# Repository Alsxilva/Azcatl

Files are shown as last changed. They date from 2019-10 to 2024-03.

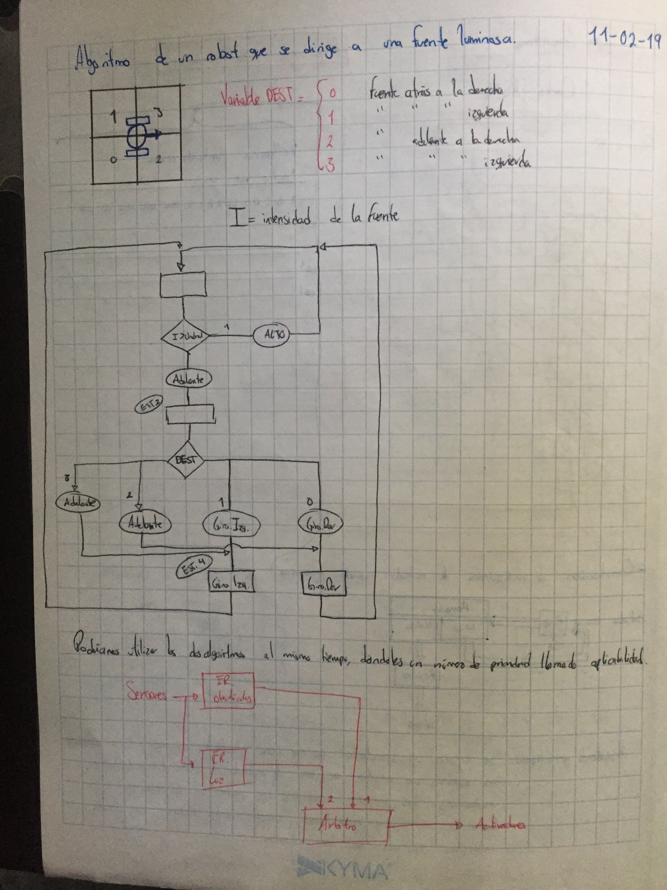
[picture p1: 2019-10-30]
Documentación/Máquinas de estado/IMG_5839.JPG

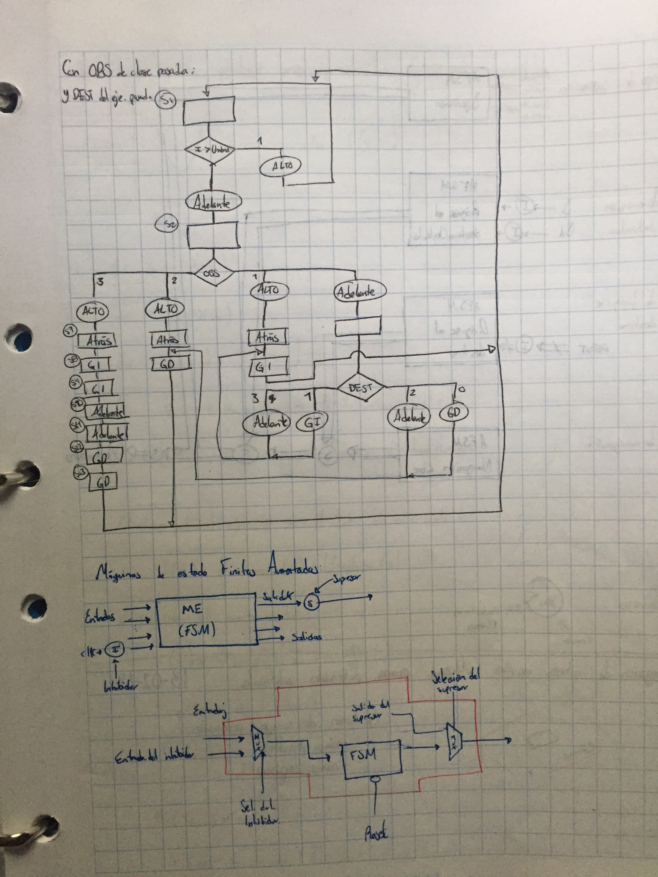
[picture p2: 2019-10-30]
Documentación/Máquinas de estado/IMG_5840.JPG

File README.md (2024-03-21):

# Azcatl 🐜 

Proyecto Azcatl de la Facultad de Ingeniería, UNAM. 
Laboratorio de Bio-Robótica.

## Encargado
Dr. Jesús Savage Carmona

## Colaboradores actuales del proyecto
* Silva Guzmán Alejandro

## Colaboradores pasados del proyecto
* Medrano Albarrán Gerardo 
* Merino Texta Rogelio de Jesús
* Silva Guzmán Edgar Roberto

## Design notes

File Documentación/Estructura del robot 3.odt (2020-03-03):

Estructura del robot

Fotoresistensias: vector de 8 elementos.

Elemento que ocupa dentro del arreglo:

Elemento del vector | Posicion en la estrella | Estado
4 | 1 | Correcto
3 | 2 | Correcto
2 | 3 | Falso: Solucionado
1 | 4 | Correcto
0 | 5 | Correcto
7 | 6 | Falso en jumper: ajustar
6 | 7 | Correcto
5 | 8 | Falso en jumper: ajustar

Reparado:

Elemento del vector | Posicion en la estrella | Estado
0 | 1 | Correcto
1 | 2 | Correcto
2 | 3 | Correcto
3 | 4 | Correcto
4 | 5 | Correcto
5 | 6 | Correcto
6 | 7 | Correcto
7 | 8 | Correcto

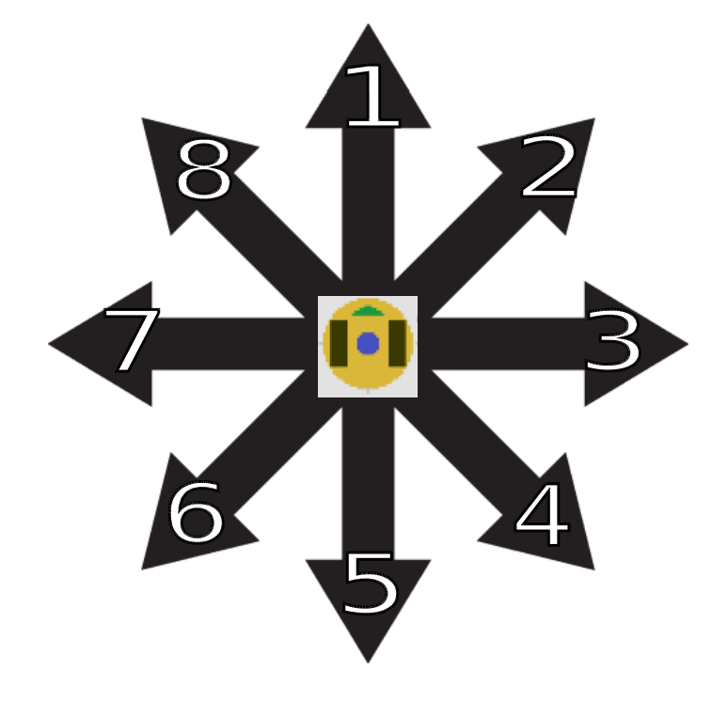
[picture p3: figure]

Intensidad de luz:

El arduino hace una conversión analógica-digital del valor entregado por las resistencias. Este valor lo recoge y lo asigna a un valor de 10 bits, siendo el valor mínimo 50 y el máximo 1023.

Si en las lecturas aparece un valor menor a 50, es que esta fotoresitencia tiene un falso contacto, seguramente en la pata unida al jumper (checar diagrama de posición de fotoresitencias).

A continuación se muestran los rangos utilizados en el programa:

Intensidad de luz | Rango | En valores que entrega arduino
Débil | 30-50% | 341 - 536
Media | 50-70% | 536 - 731
Alta | 70-90% | 731 - 875
Muy alta | 90-100% | 875 - 1023

Hokuyo

Izq: de 80 a 90°

CentralIzq: de 20 a 30°

Central: de 10 a 20 °

CentralDer: de 0 10 °

Der: -60 a -50 °

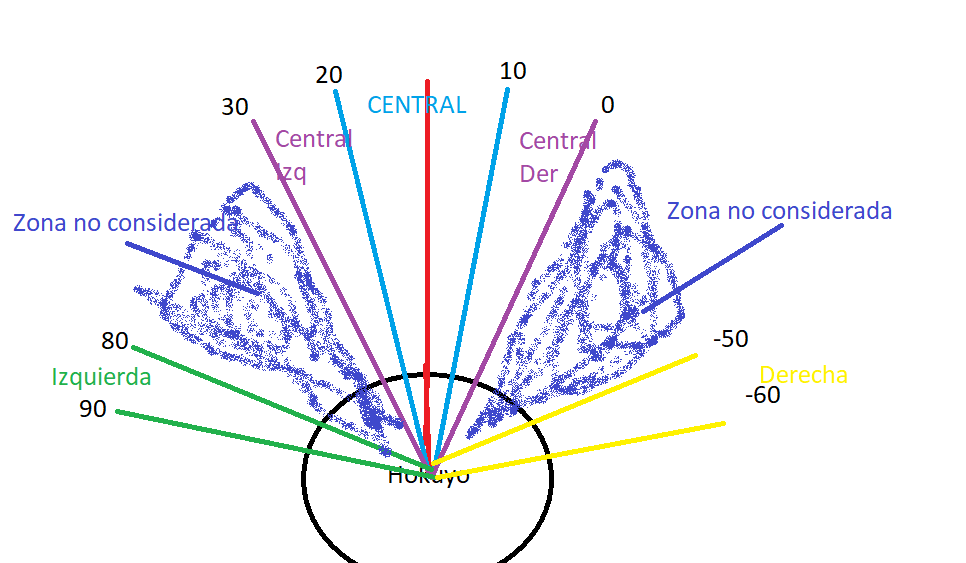
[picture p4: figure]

IMU:

Instalar para linux desde la Repo

-Demo GL: IC² y Kalman

-C++

-Python setup.py

-RTIMULib leer

Calibracion desde .exe

Regulador de voltaje:

https://www.pololu.com/product/2111

Controlador de motores:

https://www.pololu.com/product/2502/pictures

Motores:

https://www.pololu.com/product/4755/pictures

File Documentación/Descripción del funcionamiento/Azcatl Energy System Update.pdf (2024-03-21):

## Universidad Nacional Autónoma de México Posgrado de Ingeniería Laboratorio de Biorobótica

# Robot Móvil “Azcatl"

## Consumo de Energía

## A cargo de: Dr. Savage Carmona Jesús

## Realiza: Silva Guzmán Alejandro

## 19 de marzo de 2024

FACULTAD DE INGENIERÍA | 1

## I. Introducción

En el presente documento surge como respuesta y complemento al análisis del comportamiento visto en el robot Ázcatl con su configuración actual(1), la cual experimentalmente dista de su respuesta ideal. A la par del refinamiento en su Lógica de Comportamiento (2) se propone un arreglo distinto en su conexión eléctrica, pues como se describirá en los siguientes párrafos, parte de la respuesta no ideal de algunos componentes es debido a un suministro de energía erróneo.

II. Mejoras al funcionamiento.

Con el objetivo de perfeccionar el algoritmo que permita al robot rotar y trasladarse una cantidad exacta de unidades de medida (ángulo de rotación [º] o distancia [m]) se realizaron pruebas en su última configuración implementada. Pese a unos resultados parcialmente positivos durante las pruebas en el funcionamiento del robot ejecutando los algoritmos “seguidor de luz” y “evasor de obstáculos”, así como su versión de ejecución paralela, se detectaron errores y posibles mejoras, divididos en dos principales ámbitos.

II.I. Errores prácticos

Estos errores se detectaron durante la ejecución práctica de los algoritmos en el robot en un ambiente real controlado.

A. El ángulo rotado y la distancias recorridas durante estas ejecuciones fue únicamente exitoso bajo la experimentación: observación en el comportamiento, re-ajuste de parámetros y de nuevo ejecución hasta llegar al comportamiento deseado. En la mayoría de las ocasiones, aún variados los coeficientes del Perfil Trapezoidal de Movimiento, la cantidad de unidades de medida deseadas terminaron siendo casi duplicadas para alcanzar la unidad deseada.
- Ejem: Cantidad deseada: 50[cm]
Cantidad necesaria a introducir: 95[cm]

Aunque menos comunes, también se detectaron errores en los componentes:
B. Paro total en el movimiento de los seis motores. Los encoders así como los demás componentes siguen funcionando correctamente durante este error.

C. Paro parcial en el movimiento de un motor (medio-izquierda). La conexión de este motor parece estar sufriendo de un punto de conexión débil que no le suministra la energía total necesaria (Punto exacto aún no detectado). Los demás componentes siguen funcionando correctamente durante este error.
D. Pérdida de la conexión entre Ázcatl y Controlador.

II.II.Errores teóricos

Estos errores surgen tras el análisis del comportamiento erróneo del Robot, aunado a que la mayoría de los fallos ocasionales están más relacionados a la parte eléctrico-mecánica.

1. Se encontró que la energía necesaria para una ejecución de máxima eficiencia en los motores es de 12[V] mientras que se les estaba suministrando 7.4[V], lo que supone una variación en la energía otorgada y por lo tanto en el comportamiento final de los motores.

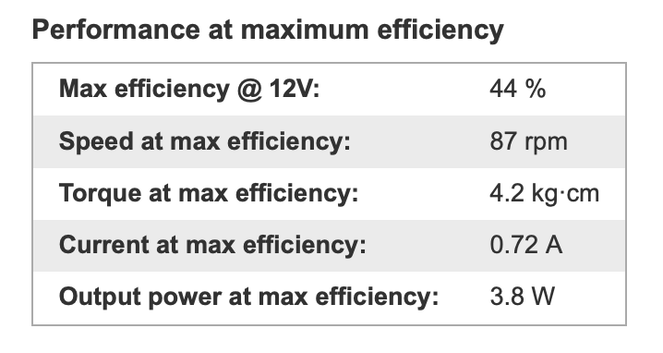
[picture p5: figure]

2. Fallo de suministro de energía. Las baterías utilizadas ya muestran signos de deterioro, y a pesar de servir parcialmente lo más probable es que ya no funcionen ni cerca de su comportamiento ideal, derivando en fallos del suministro de energía total necesaria para el robot y finalmente en alguno de los errores listados anteriormente (Errores A, B, C y D).

En vías de llegar al comportamiento óptimo del robot se propone una conexión eléctrica distinta con un suministro eléctrico distinto como resolución principal al problema planteado, anteponiéndose por ahora a la resolución por software (implementación de un IMU). Estas propuestas se describen en el punto final y siguiente.

1.1 Pololu Gearmotor 37Dx73L Datasheet

III. Análisis y cálculo del consumo de energía por módulos.

Se propone dividir la conexión eléctrica en dos módulos, alimentados por 12 [V] y 5 [V] respectivamente.

Este arreglo nos permite dividir los componentes de consumo alto y variable (motores) de los de consumo normal y continuo (CPUs y periféricos), lo cual nos brinda las siguientes ventajas:

- Motores trabajando con el Voltaje de máxima eficiencia para movimientos más exactos.
- Mayor potencia en los motores que permitirá reducir tiempos de ejecución.
- Permitirá una identificación más sencilla de los problemas en ejecución gracias al aislamiento por módulos.
- Protección de nuestras tarjetas ante alguna sobrecarga o falta de energía gracias al aislamiento por módulos.
- Conexión de un mayor número de periféricos para trabajos futuros (IMU, Control, etc).
- Mejora drástica en el aprovechamiento de energía de las baterías.

12[V]

6 Pololu Gearmotor

5[V]

2 LEDs
Hokuyo
Arduino Mega
Raspberry pi 3+

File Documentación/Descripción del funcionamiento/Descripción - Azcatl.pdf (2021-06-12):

## Universidad Nacional Autónoma de México Posgrado de Ingeniería Laboratorio de Biorobótica

# Robot Móvil “Azcatl"

## Servicio Social

# Reporte de modificaciones

## A cargo de: Dr. Savage Carmona Jesús

## Realiza: Silva Guzmán Alejandro

## 23 de Marzo de 2020

FACULTAD DE INGENIERÍA | 1

## Reporte de modificaciones

1. Reparación y sustitución de torre de fotoresistencias
El elemento presentaba fallas constantemente debido al desgaste de los componentes: había cables “jumpers” muy desgastados a las puntas, lo cual provocaba un falso contacto; algunas fotoresistencias presentaban fallos en sus pines, las cuales fueron sustituídas.
Además se sustituyó la antigua estructura (taparrosca redonda) dado que no brindaba el espacio necesario para un acomodo adecuado de las fotoresistencias. Y finalmente se agregaron dos luces led que indican el estado Encendido/Apagado del Arduino.
La torre quedó de la siguiente manera.

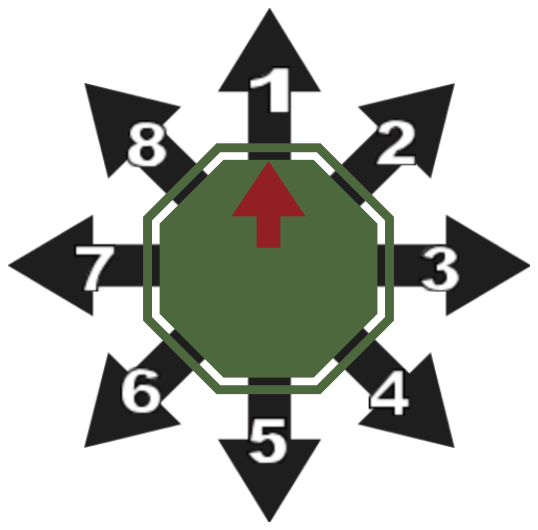
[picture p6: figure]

Figura muestra el orden de las fotoresistencias y la posición de cada una de ellas dentro del arreglo usado por el algoritmo.

2. Elaboración de nuevos cables de alimentación desde baterías muertas (inservibles)
Se pidió la nueva batería que se requerían para el funcionamiento prolongado del robot: 7.4[V] con capacidad de 5000[mA]. Misma que requería una conexión de alimentación “XT30”; se adaptó a la conexión que ya tenía el robot, que es la “T-System AWG12”:
3. Documentación de códigos “Arduino control”, “carrito_node”, “simple_move_node”. Estos códigos fueron realizados anteriormente, pero no contaban con un formato adecuado, ni con comentarios que facilitaran su entendimiento.
4. Se le realizó mantenimiento diversas partes del robot:
- Ajuste de llantas: estaban ya fuera de su posición.
- Ajuste de esqueleto del robot: estaba desajustado y desnivelado.

- Agregué soporte a motores de las 6 llantas del robot: se agregó una escuadra metálica a cada uno de los motores en las llantas, pues por el desgaste, los ejes de las llantas ya estaban fuera de su posición, provocando que cada llanta girara en sentidos distintos, provocando una desviación significante en el comportamiento del robot.
Desviación apreciable en largas distancias rectas: el robot se desviaba aproximadamente 15[cm] a la derecha por 1[m] recorrido en línea recta.
Estos soportes mejoran en gran medida este comportamiento, obteniendo una desviación de menos de 3[cm] por metro recorrido en línea recta.
*Insertar foto de los soportes de las llantas”
5. Creación de nodo “simple_move_2”.
Este nuevo nodo de ROS fue hecho específicamente para calibrar el movimiento del robot. En él, únicamente se indican por teclado los siguientes parámetros:
- El número de pasos
- La distancia (en metros) por paso
- El ángulo (en grados) por paso
- Las constantes “K” para el control PID
6. Creación de nodos de comportamiento reactivo: “evasor_obstaculos_hokuyo” y “seguidor_de_luz”.
6.1.Para el nodo de evasión de obstáculos se utilizó parte de la máquina de estados utilizada para el seguimiento de color en el proyecto pasado.
Para este nodo el usuario ingresarán cuatro parámetros: el número de pasos, la distancia y ángulo de giro (por paso) y la distancia a detectar los obstáculos.
La visión del láser Hokuyo se es la siguiente:

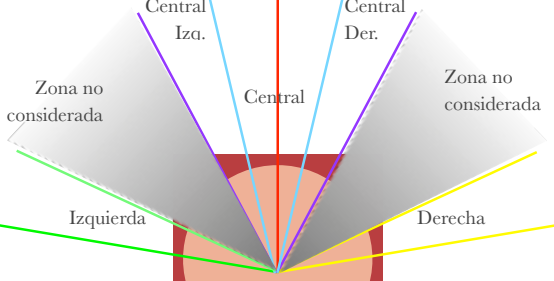
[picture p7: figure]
Izquierda; Derecha; Zona no considerada; Izq.; Central; Der.

Se hace un barrido para detectar la o las zonas de dónde se encuentra un posible

Hokuyo

Central

Central

obstáculo.
El algoritmo está descrito como se muestra a continuación:

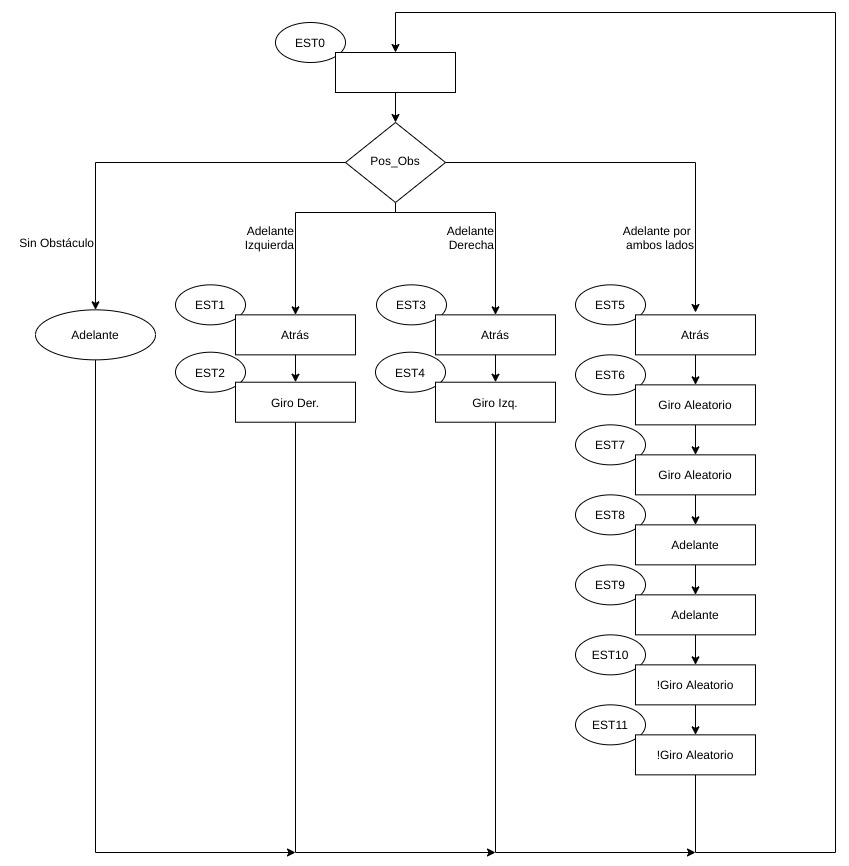
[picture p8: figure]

6.2.Para el nodo de seguimiento de luz, el usuario ingresarán cuatro parámetros: el número de pasos, la distancia y ángulo de giro (por paso) y la intensidad a detectar la luz los obstáculos.
El algoritmo está descrito como se muestra a continuación:

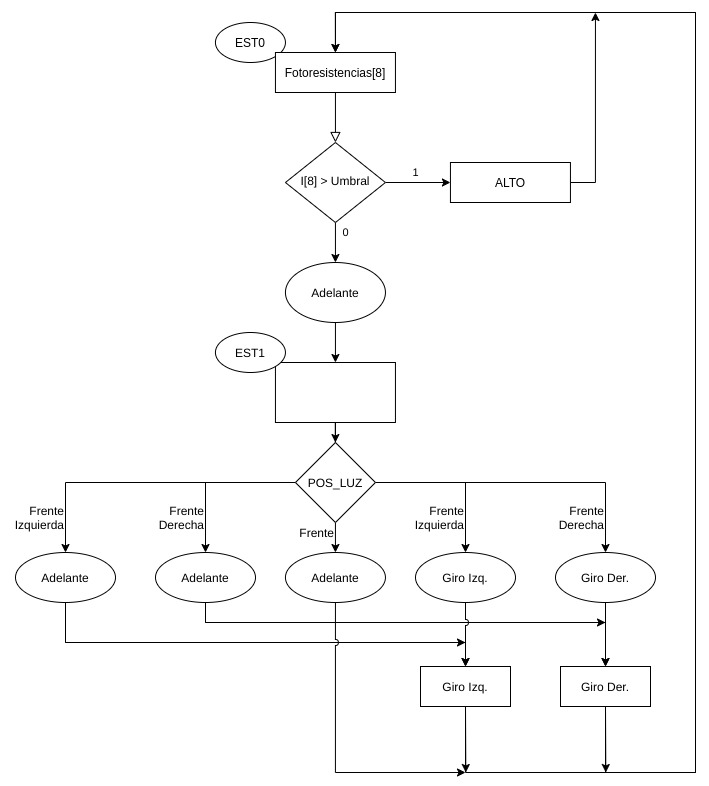
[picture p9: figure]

7. Implementación de un USB hub para correcta alimentación de Arduino y Hokuyo del robot Azcatl.
Anteriormente estos dispositivos de alimentaban directo de la tarjeta RaspberryPi, pero constantemente había un fallo: los puertos USB de esta tarjeta están limitados a cierta potencia, y al llegar al límite, ocasionaba un parón en los motores y en la Arduino, perdiendo la comunicación entre ellos y fallando así por completo la ejecución del algoritmo en uso.
8. Creación de nuevo repositorio en Github
La liga es la siguiente:
https://github.com/Alsxilva/Azcatl

En este repositorio fui registrando todos los avances durante el servicio social:
- Documentación del código: ordenar y comentar el código ya implementado para su mejor y más fácil entendimiento
- Actualización constante de nuevos nodos creados “simple_move_2”, “seguidor_luz” y “seguidor_obstaculos”.
- Almacenamiento de archivos importantes del Azcátl: archivo de descripción .PDF y demás documentación necesaria.

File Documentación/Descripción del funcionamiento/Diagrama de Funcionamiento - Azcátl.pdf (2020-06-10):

## Universidad Nacional Autónoma de México Posgrado de Ingeniería Laboratorio de Biorobótica

# Robot Móvil “Azcatl"

## Servicio Social

# Diagrama de Funcionamiento

## A cargo de: Dr. Savage Carmona Jesús

## Realiza: Silva Guzmán Alejandro

## 20 de abril de 2020

FACULTAD DE INGENIERÍA | 1

## Descripción

1. Estructura
El robot Azcatl cuenta con dos principales unidades de procesamiento:
- Una RaspberryPi 3
- Arduino Mega
A su vez, el Arduino cuenta con un elemento de control para los motores:
- Pololu Dual VNH5019 Motor Driver Shield para Arduino
Y la distribución de funcionamiento se describe en el siguiente diagrama:

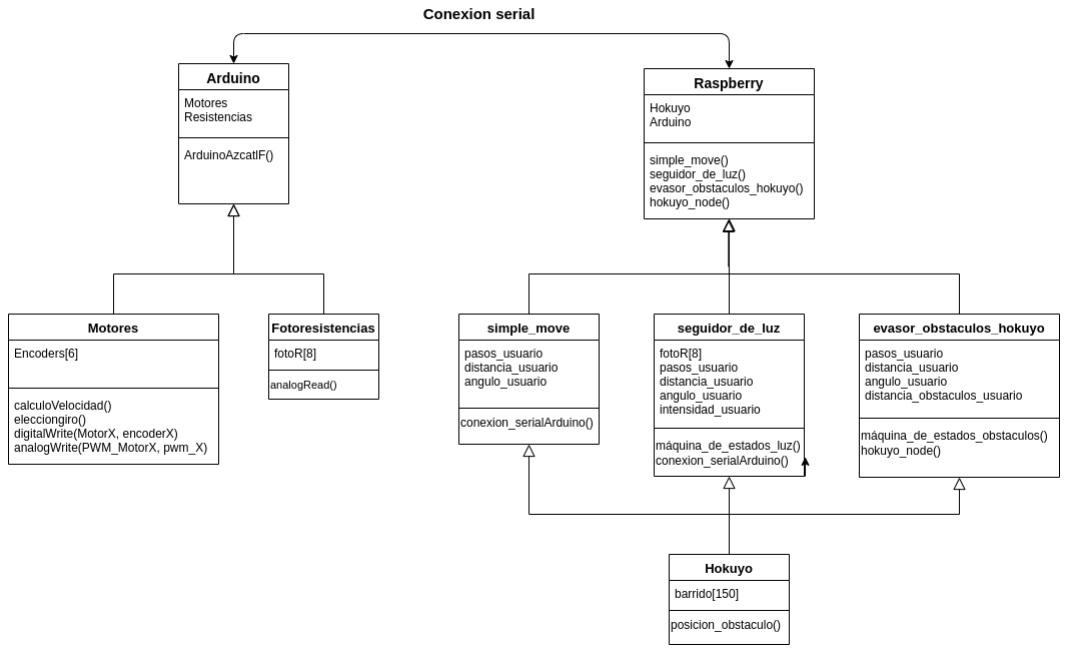
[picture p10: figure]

2. Conexión serial
Anteriormente la comunicación entre el Arduino y la Raspberry se realizaba mediante ROS. Se iniciaba un nodo desde el Arduino en el cual se publicaban y se recibían los datos. Esta misma estructura tuvo ciertas limitaciones: al intentar publicar más datos, nos encontramos con un tope en el ancho de comunicación, pues el tamaño del buffer mediante el cual se transmitían los datos se era insuficiente. Esto, además de impedir la prueba de algunos algoritmos dentro del robot, llegó a causar la nula sincronización y/o desconexión entre las tarjetas, por lo cual se cambió la manera en que estos se comunican.
Esta conexión ahora es directa por el puerto serial (USB 2.0 Type-B) por la que se conectan las tarjetas.

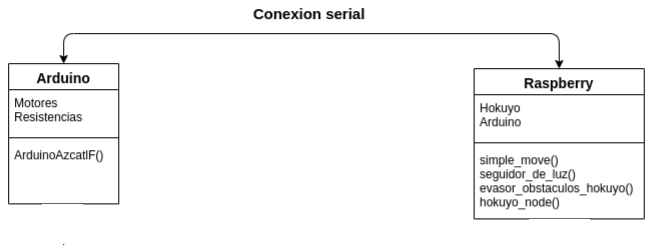
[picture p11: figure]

3. Arduino Mega

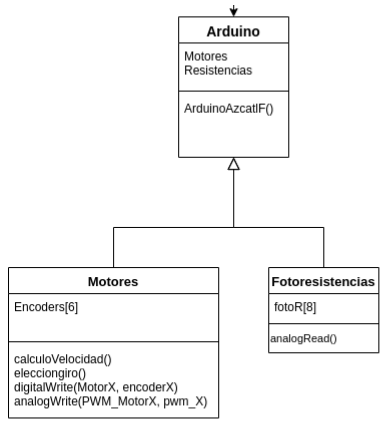
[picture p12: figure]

El Arduino Mega se encargará de:
- El control de motores
Este lo realizará con ayuda del “Pololu Dual VNH5019 Motor Driver Shield”: este
entregará una alimentación continua de | (misma que no es posible suministrar
directamente del Arduino) y proporcionará directamente a la tarjeta las líneas de control para manipular correctamente los motores.

12.1[V ]

- El procesamiento de datos desde los Encoders
Con la información desde el algoritmo en funcionamiento (perfil trapezoidal de Velocidad del robot desde Raspberry) calculará la velocidad y su traducción a PWM, así como la dirección de giro de llantas y una retroalimentación mediante el control PID, anteriormente implementado.
Para todo ello es necesario el procesamiento de los pulsos desde los Encoders descritos a continuación.

Encoders de cuadratura

Funcionan mediante el principio del efecto Hall:
Los sensores de efecto Hall son transductores que generan un voltaje de salida en respuesta a la presencia de un campo magnético variable.

Estos encoders generan 2 señales de onda cuadrada:
— A y B, con un desfasamiento de 90° entre ellas.
Estas 2 señales son leídas por un sistema microcontrolador (Arduino Mega), el cual puede calcular tanto la velocidad en revoluciones por minuto (RPM), la posición del eje y el sentido de giro.

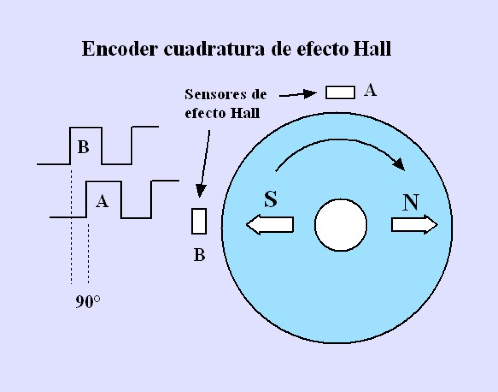
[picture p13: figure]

Nuestros encoders entregan | (Cuentas/pulsos por revolución) entre los dos.
Lo que significan | después de la proporción de tamaño con el eje del motor
que es: Dado que Entonces | 64[CPR]

### 6533[CPR]

102.08 : 1
PPR = CPR
4

### PPR = 6544[CPR] 4 = 1636[PPR]

- Con estos datos (en teoría) podremos indicar al robot distancias y ángulos deseado a navegar.
*Esta información se puede verificar en el sitio oficial de Pololu citada el final del documento.
- Lectura analógicas desde fotoresistencias
El Arduino cuenta con pines de lectura analógica, los cuáles asignan valores a determinado nivel de voltaje recibido en ellos, y que va desde 0 hasta 1023. Con este valor se determinará la intensidad de luz captada en cada una de las fotoresistencias, se enviará a la Raspberry y así se ubicará el destino luminoso.
4. RaspberryPi 3
La tarjeta realizará el cálculo de datos recibidos desde el Arduino y el Hokuyo.
Utilizará estos datos para realizar correctamente cada uno de los comportamientos reactivos ya programados, mismos que se ubican en la siguiente imagen.

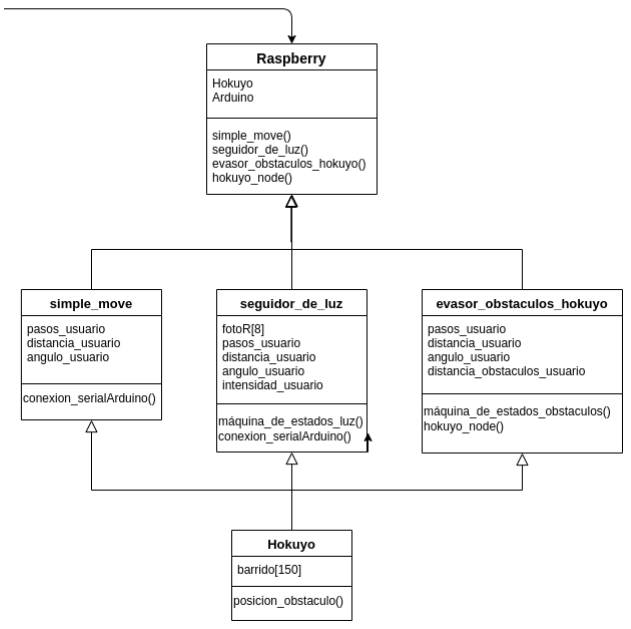
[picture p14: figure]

5. El proceso con el que trabajan conjuntamente las tarjetas es el siguiente:
a) Se ejecuta el algoritmo de comportamiento deseado.
b) Para cada uno de los comportamientos se requiere que el usuario ingrese algunos datos para que el robot actué de una manera deseada en específico: distancia, pasos, ángulo de giro y intensidad de luz o distancia a detectar objetos (dependiendo del algoritmo seleccionado)
c) Se hace una lectura de datos desde Hokuyo y/o fotoresistencias, para calcular siguiente movimiento.
d) La Raspberry captura y analiza estos datos.
e) Calcula con ellos el perfil trapezoidal de movimiento para realizar cada paso.
f) Se regresan estos datos a la tarjeta Arduino y los aplicará sobre los motores.
g) Retroalimentación mediante el control PID en motores para mejorar comportamiento.

Referencias:
- https://www.puntoflotante.net/FUNCIONAMIENTO-ENCODER-CUADRATURA-EFECTO-HALL.htm (https://www.puntoflotante.net/FUNCIONAMIENTO-ENCODER-CUADRATURA-EFECTO-HALL.htm)
- https://www.pololu.com/docs/0J70/3.4
- https://www.pololu.com/product/4755

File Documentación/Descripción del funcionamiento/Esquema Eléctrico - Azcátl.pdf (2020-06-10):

## Universidad Nacional Autónoma de México Posgrado de Ingeniería Laboratorio de Biorobótica

# Robot Móvil “Azcatl"

## Servicio Social

# Diagrama eléctrico

## A cargo de: Dr. Savage Carmona Jesús

## Realiza: Silva Guzmán Alejandro

## 20 de abril de 2020

FACULTAD DE INGENIERÍA | 1

## Diagrama eléctrico

1. Niveles
La estructura del robot permite la división del circuito eléctrico en dos niveles: superior e inferior.

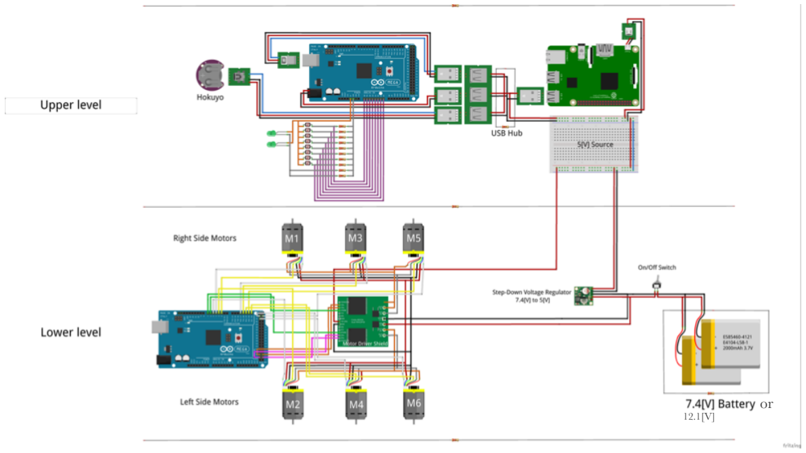
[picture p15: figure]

Diagrama general

1.1.El nivel inferior almacena el bloque de alimentación de todo el robot:
- Pila de | (Pila negra) o | (Pila azul).
- Regulador de voltaje a
- Controlador para los motores.

1.2.El bloque superior contiene los elementos de control, recepción y procesamiento de datos:
- RaspberryPi 3
- Arduino Mega
- Hokuyo
- Torre de Fotoresistencias
7.4[V ] | 12.1[V ]
5[V ]

2. Descripción por bloques 2.1.Alimentación

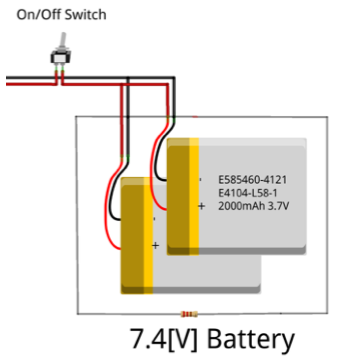
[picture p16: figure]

La alimentación del robot viene de una batería de LiPo de 2 celdas con capacidad de
y voltaje de de | cada una, las cuales conectadas en serie nos entregan
(Pila negra) o | (Pila azul).

2.2.El robot cuenta con un switch para el encendido/apagado del robot.
Una vez presionado, la RaspberryPi 3, el Hub USB, el Arduino Mega y el láser Hokuyo se encenderán inmediatamente.
5200[m A] | 3.7[V ]
7.4[V ] | 12.1[V ]

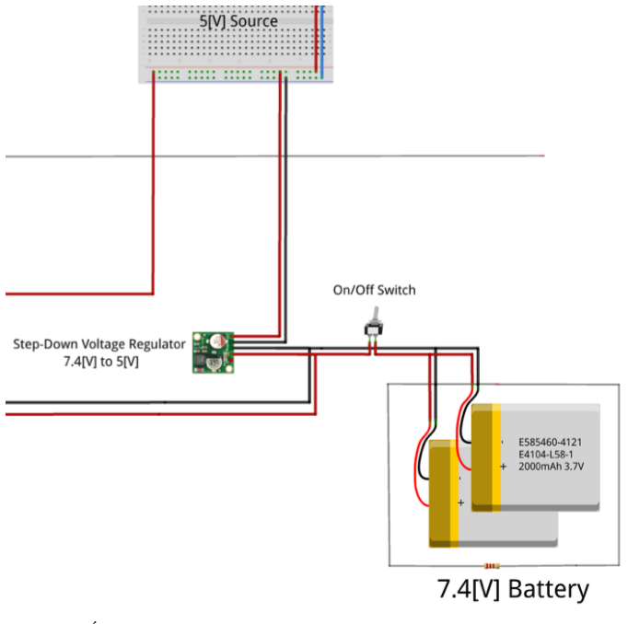
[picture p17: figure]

2.3.Regulador de voltaje
Se utilizó un regulador de voltaje “Pololu D15V70F5S3”
Documentación: https://www.pololu.com/product/2111
Este puede recibir una alimentación desde | y hasta | , y la reduce hasta un
voltaje seleccionado por el usuario de | o | .

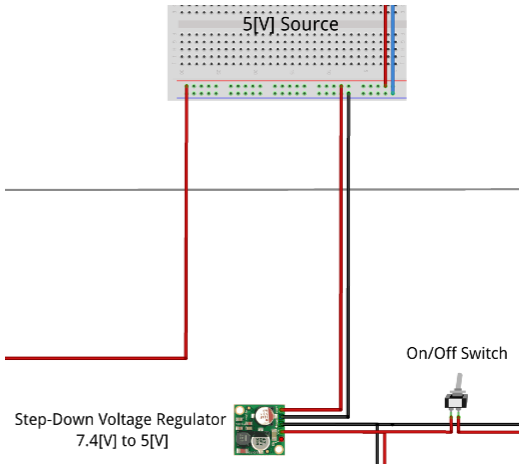
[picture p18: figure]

Para este robot la configuración de salida será de | para la correcta alimentación de
los elementos de procesamiento de datos a RaspberryPi 3 y Arduino Mega.
Si se desease utilizar la configuración de únicamente se debe de alimentar el pin “3V3 SELECT” del regulador.

2.4.Alimentación de elementos de procesamiento de datos: RaspberryPi 3 y Arduino Mega. Ambas tarjetas requieren de una alimentación de para su correcto funcionamiento. Este voltaje es entregado por el regulador hasta una miniProtoboard que se encuentra a un costado de la RasperryPi 3, desde la cual se alimentarán las dos tarjetas.
La conexión se muestra a continuación:

4.5[V ] 24[V ]
3.3[V ] 5[V ]

5[V ]

3.3[V ]

5[V ]

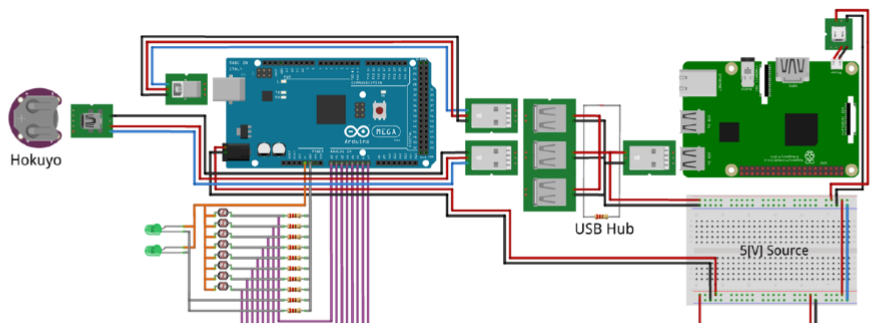
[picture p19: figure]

En un principio el Arduino era alimentado únicamente mediante su conexión USB 2.0 Type-B, pero en ocasiones se lanzaba un error de sincronización.
Al parecer, la alimentación necesaria para el Arduino, los motores, el Hokuyo y las resistencias, no era suficiente desde la RaspberryPi 3, ocasionando que se apagara la tarjeta o se congelara el proceso. Para solucionar esto, se conectó la alimentación del Arduino directo a la Protoboard que entrega los .

2.5.Conexión de los motores:
- “100:1 Metal Gearmotor 37Dx73L mm 12V with 64 CPR Encoder”
- Documentación: https://www.pololu.com/product/4755

Con:
- “Pololu Dual VNH5019 Motor Driver Shield para Arduino”
- Documentación: https://www.pololu.com/product/2502
Y hasta el Arduino Mega. Las conexiones se muestran a continuación:

5[V ]

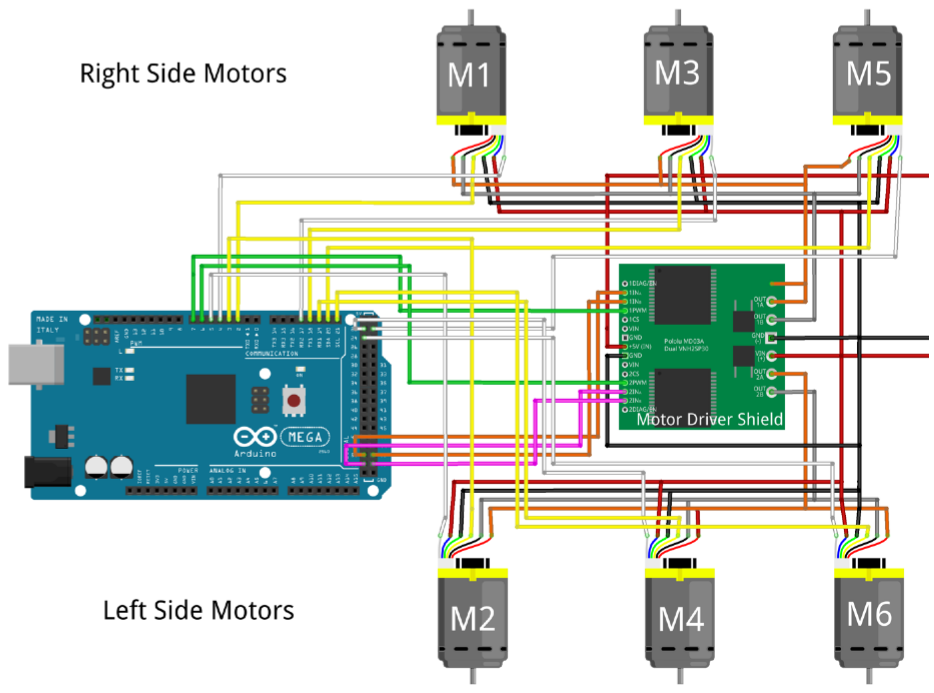
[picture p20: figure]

Los motores Pololu reciben una alimentación de | o | , dependiendo de la
batería conectada. La alimentación que se les puede administrar inicia desde los | ,
pero están pensado para trabajar con | .
La diferencia en rendimiento se describe en la tabla de a continuación:

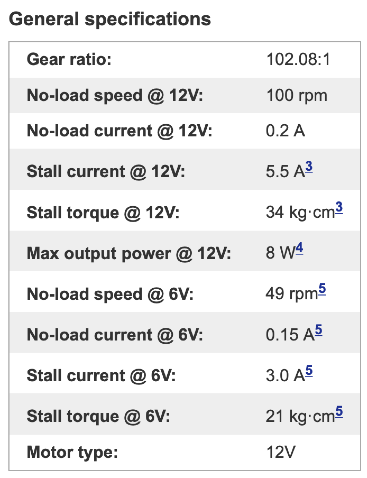
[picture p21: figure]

Tabla obtenida desde el sitio web de Pololu.

Estos cuentan con un encoder de cuadratura de | , mismo que se comunica
directamente al Arduino.

La información de los cables que vienen desde los motores es la siguiente:

12.1[V ] 7.4[V ]
6[V ]
12[V ]

### 64[CPR]

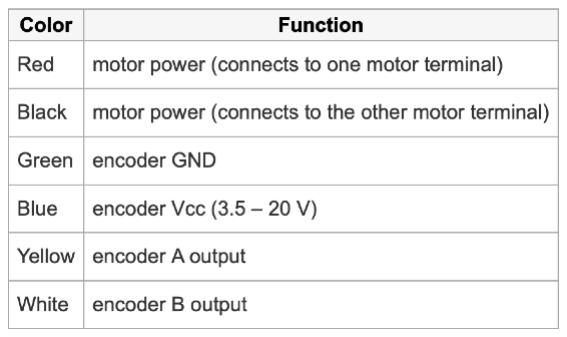
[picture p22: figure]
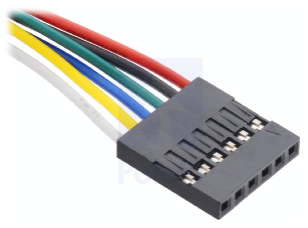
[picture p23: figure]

Las conexiones de los encoders van directo al Arduino, y vienen dadas por la siguiente tabla:

Las conexiones hacia el Pololu Dual VNH5019 Motor Driver Shield hasta el Arduino vienen dadas por la siguiente tabla:

Pin Arduino | Pin Motor
2 | Encoder A — Motor 1
4 | Encoder B — Motor 1
3 | Encoder A — Motor 2
5 | Encoder B — Motor 2
18 | Encoder A — Motor 3
17 | Encoder B — Motor 3
19 | Encoder A — Motor 4
22 | Encoder B — Motor 4
20 | Encoder A — Motor 5
23 | Encoder B — Motor 5
21 | Encoder A — Motor 6
24 | Encoder B — Motor 6
Pin Arduino | Pin Motor Driver Shield
6 | PWM 1 — Lado Derecho
7 | PWM 2 — Lado Izquierdo
48 | 2-IN-A — Lado Izquierdo
49 | 2-IN-B — Lado Izquierdo
50 | 2-IN-A — Lado Derecho
51 | 2-IN-B — Lado Derecho

2.6.Conexión de las Fotoresistencias:
El robot cuenta con un arreglo de 8 fotoresistencias conectadas a las entradas con lectura analógicas del Arduino. Estar permiten leer un voltaje de hasta desde las resistencias. La conexión es la siguiente:

Y en la tabla:

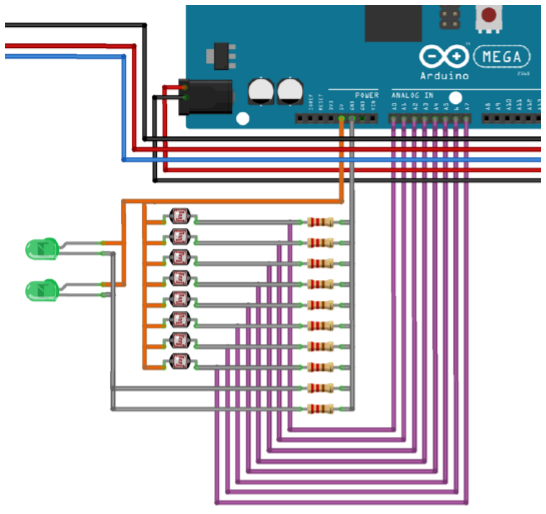
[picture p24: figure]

Anexado al diseño anterior, se colocaron dos luces Led color verde, que permite visualizar el estado de (Encendido o Apagado) del Arduino. Estas únicamente se alimentan desde el pin de .

5[V ]

5[V ]

Pin Arduino | Torre de resistencias
A0 | Fotoresistenca 1
A1 | Fotoresistenca 2
A2 | Fotoresistenca 3
A3 | Fotoresistenca 4
A4 | Fotoresistenca 5
A5 | Fotoresistenca 6
A6 | Fotoresistenca 7
A7 | Fotoresistenca 8

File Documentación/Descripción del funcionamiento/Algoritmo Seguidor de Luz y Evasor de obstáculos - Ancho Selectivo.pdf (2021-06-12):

## Universidad Nacional Autónoma de México Posgrado de Ingeniería Laboratorio de Biorobótica

# Robot Móvil “Azcatl"

## Servicio Social

## Descripción de algoritmo “Evasor de Obstáculos y Seguidor de Luz”

## A cargo de: Dr. Savage Carmona Jesús

## Realiza: Silva Guzmán Alejandro

## 9 de junio de 2021

FACULTAD DE INGENIERÍA | 1

# Descripción general

Este documento presenta la descripción de la unión de los dos algoritmos reactivos realizados previamente: “Evasor de obstáculos” y “Seguidor de luz”. Una vez se realizaron las pruebas necesarias para determinar su buen funcionamiento se realizó este tercer algoritmo.

Este nuevo código no presenta nuevos parámetros ni variables, únicamente la unión de todos los elementos que conformaban a los algoritmos reactivos ya mencionados.

El nuevo código se describe a continuación.

### Inserción de datos por el usuario:

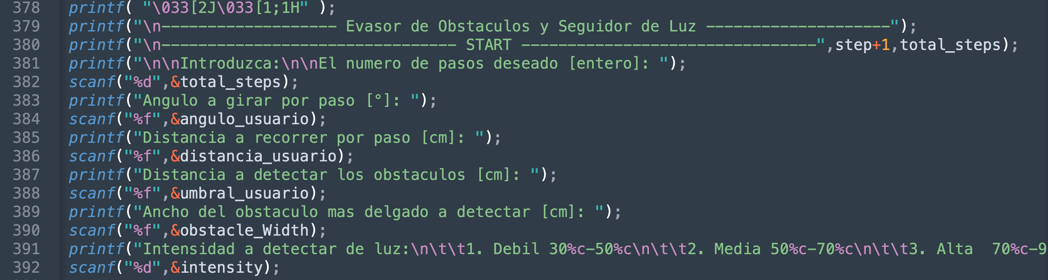
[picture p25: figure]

Se observa que hay una unificación en cuanto a todos los datos que requiere el algoritmo en esta sección que va de la línea 378 hasta la 392.
Recalcar que se mantiene la modalidad de “ancho deseado” agregada ya en el algoritmo “Evasor de Obstáculos” como también la modalidad de “intensidad de luz deseada” vista en el algoritmo “Seguidor de Luz”.

### Booleanos de conexión:

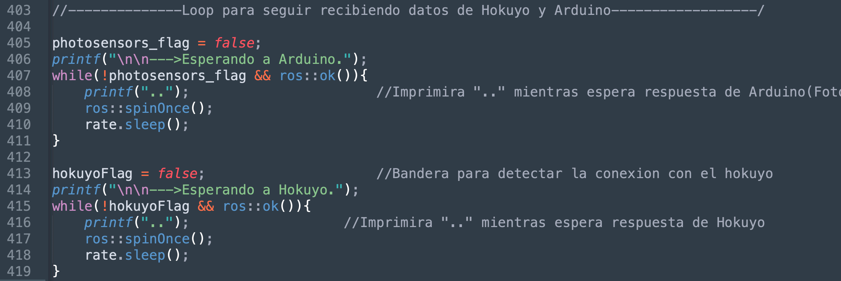
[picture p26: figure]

Se agregan ahora dos métodos iterativos para detectar la conexión con los dos controladores del Ázcatl: Arduino y Hokuyo. En ellos se emplean dos variables booleanas para detectar la conexión efectiva con estos componentes.
Dichos dos ciclos utilizan las siguientes funciones:

Mismas que trabajarán a la par con la nueva máquina de estados.

Función | Línea | Controlador
callbackPhotosensors() | 58 | Arduino
data_photosensors() | 141 | Arduino
callbackHokuyo() | 216 | Hokuyo
data_hokuyo() | 334 | Hokuyo

## Máquina de estados: Evasor de obstáculos y seguidor de Luz


El nuevo algoritmo de describe con la siguiente carta ASM:

Carta ASM del Algoritmo Evasor de Obstáculos y Seguidor de Luz

### Explicación Breve del algoritmo:

Se observa que la estructura básica de los dos algoritmos anteriormente usados se mantendrá, dándole prioridad al algoritmo Evasor de Obstáculos. Si y sólo si se encuentra el camino libre de obstáculos se procederá a buscar la fuente de luz y actuar en consecuencia para encontrarla, entrando en acción el algoritmo Seguidor de Luz.

Posición Ancho del obstáculo a detectar [cm]

Distancia
del
obstáculo
[cm]

Lecturas
necesarias

Lecturas
detectadas

¿Obstáculo?

A | 10 | 50 | 32 | 13 | FALSE
B | 4 | 50 | 13 | 13 | TRUE

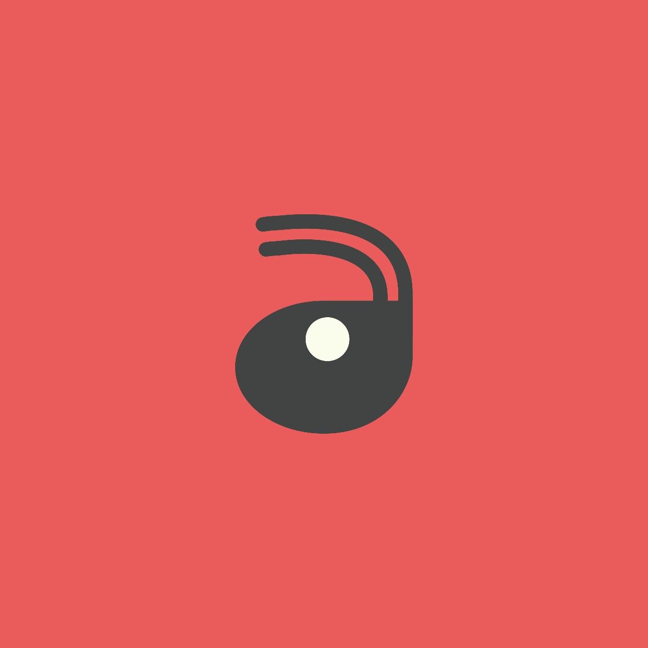
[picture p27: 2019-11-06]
Documentación/Ant eye.jpg

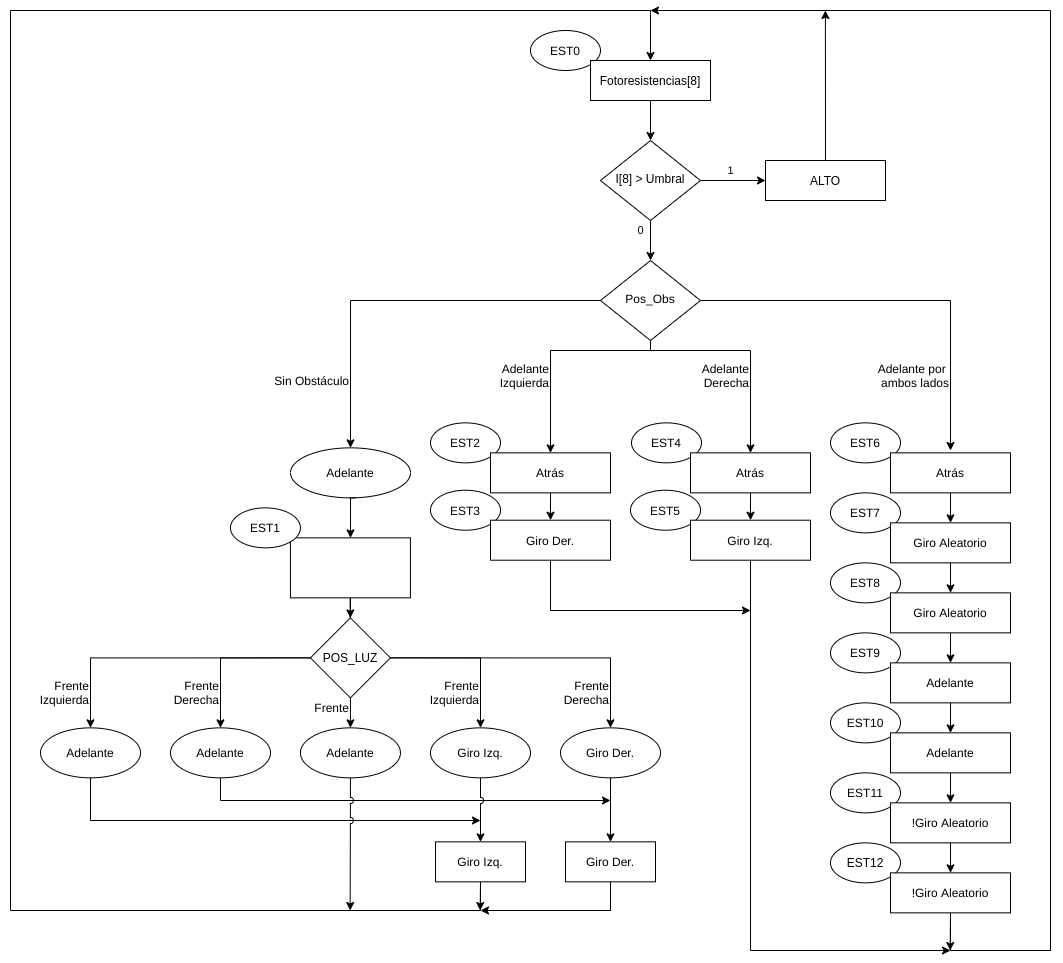
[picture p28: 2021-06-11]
Documentación/Máquinas de Estado - Draw IO/Evasor de obstáculos y seguidor de Luz con Transparencia.png

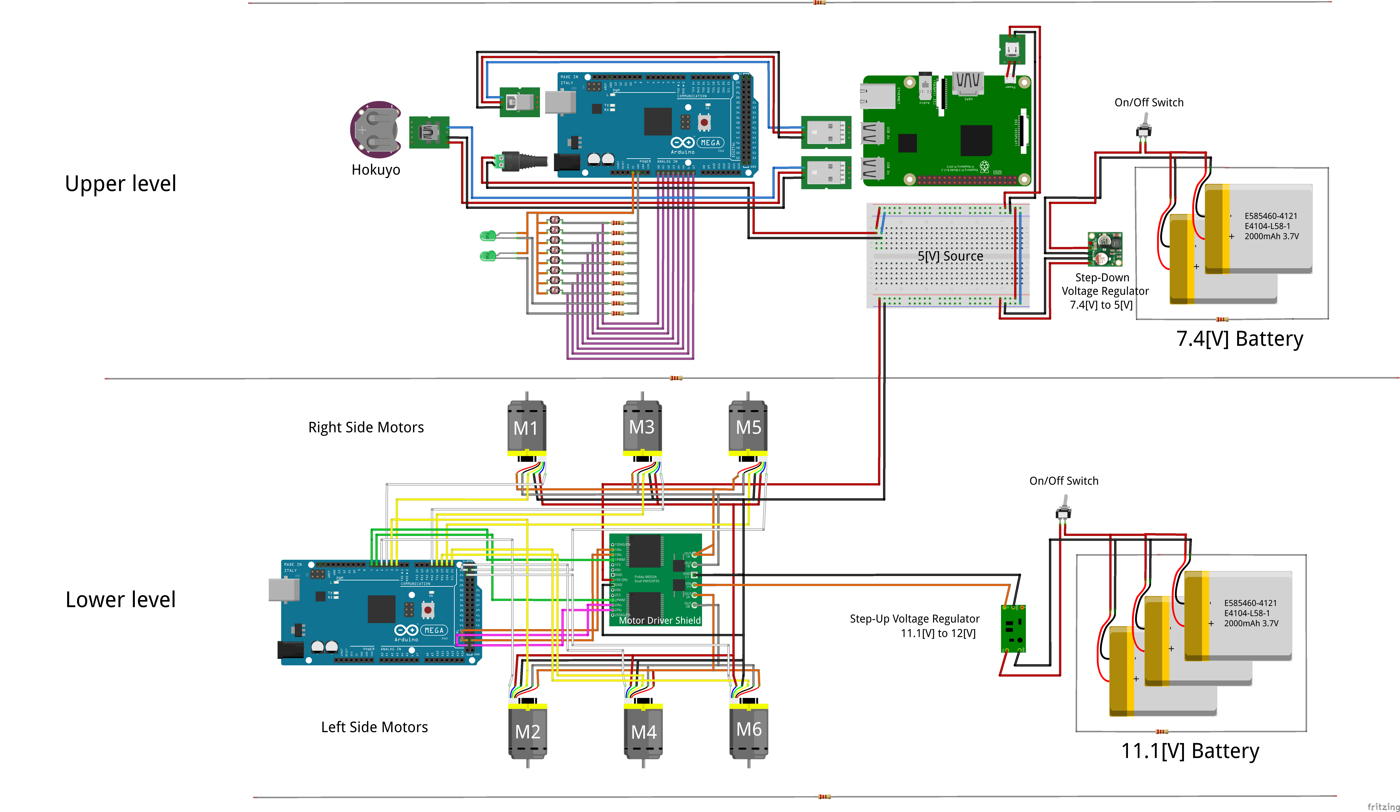
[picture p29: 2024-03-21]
Documentación/Diagrama eléctrico - Fritzing/Diagrama eléctrico Doble Batería.png

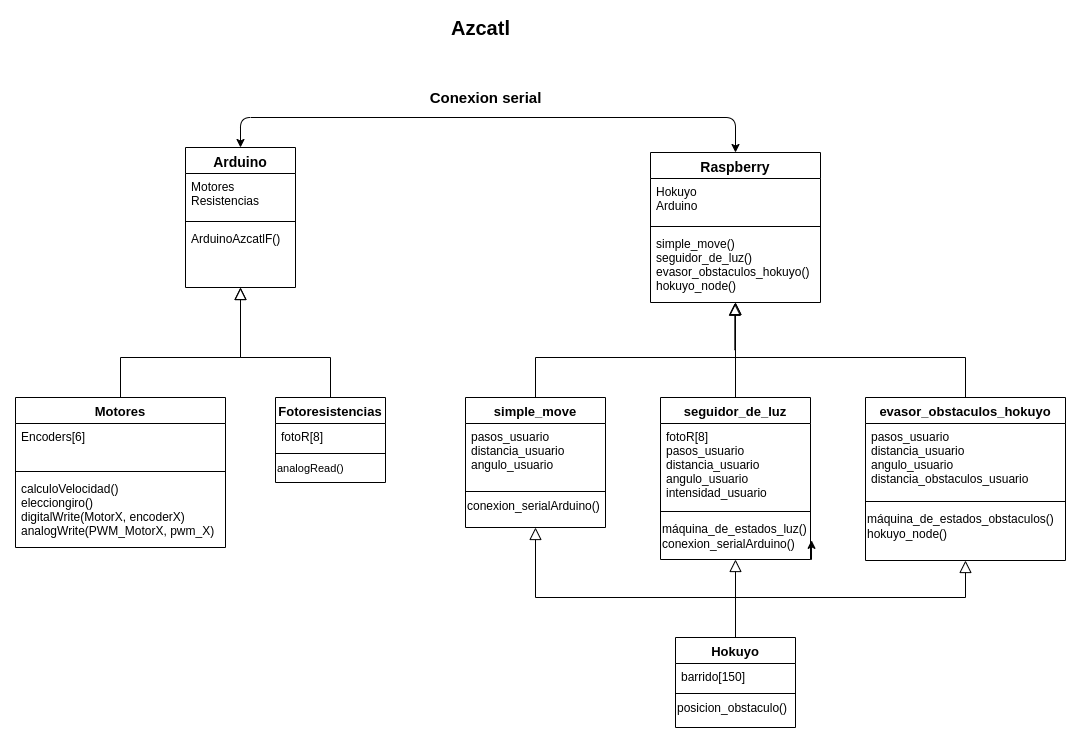
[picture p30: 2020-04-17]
Documentación/Diagrama de clases/Diagrama de clases Azcatl 2.png

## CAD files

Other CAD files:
Azcatl-master/CAD_Model/Arduino_Mega.prt
Azcatl-master/CAD_Model/Azcatl.prt
Azcatl-master/CAD_Model/Base_LDR.prt
Azcatl-master/CAD_Model/Base_acrilico.prt
Azcatl-master/CAD_Model/Cajita_proto.prt
Azcatl-master/CAD_Model/Columna.prt
Azcatl-master/CAD_Model/Cople.prt
Azcatl-master/CAD_Model/Driver.prt
Azcatl-master/CAD_Model/Ensamble_acrilico.prt
Azcatl-master/CAD_Model/Hokuyo.prt
Azcatl-master/CAD_Model/LDR.prt
Azcatl-master/CAD_Model/Llanta_goma.prt
Azcatl-master/CAD_Model/Llanta_puntas.prt
Azcatl-master/CAD_Model/Llanta_puntas_plana.prt
Azcatl-master/CAD_Model/Llanta_puntas_plana_redondeo.prt
Azcatl-master/CAD_Model/Llanta_terreno.prt
Azcatl-master/CAD_Model/Media_base_acrilico.prt
Azcatl-master/CAD_Model/Motor.prt
Azcatl-master/CAD_Model/Parrila_2.prt
Azcatl-master/CAD_Model/Parrilla_1.prt
Azcatl-master/CAD_Model/Parrilla_Cajuela.prt
Azcatl-master/CAD_Model/Pila.prt
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

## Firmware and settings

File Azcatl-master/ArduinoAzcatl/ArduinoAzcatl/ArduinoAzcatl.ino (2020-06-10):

/*---------------------------------------------------------------Librerías---------------------------------------------*/
#include <ros.h>
#include <std_msgs/Float32MultiArray.h>
#include <std_msgs/Int64.h>
/*--------------------------------------------------------------Constantes----------------------------------------------*/
//Motores
#define PWM_MotorD 7 //Velocidad de los motores Derechos
#define PWM_MotorI 6 //Velocidad de los motores Izquierdos
#define MotorD_A 50 //Direccion de los motores Derechos A
#define MotorD_B 51 //Direccion de los motores Derechos B
#define MotorI_A 48 //52->48 //Direccion de los motores Izquierdos A
#define MotorI_B 49 //53->49//Direccion de los motores Izquierdos B
//Enconders
//Motor 1 --> Enfrente Derecha
#define Enc_M1A 2//Interrup0
#define Enc_M1B 4
//Motor 2 --> Enfrente Izquierda
#define Enc_M2A 3//Interrup1
#define Enc_M2B 5
//Motor 3 --> Medio Derecha
#define Enc_M3A 18//Interrup5
#define Enc_M3B 17
//Motor 4 --> Medio Izquierda
#define Enc_M4A 19//Interrup4
#define Enc_M4B 22
//Motor 5 -->  Atras Derecha
#define Enc_M5A 20//Interrup3
#define Enc_M5B 23
//Motor 6 --> Atras Izquierda
#define Enc_M6A 21//Interrup2
#define Enc_M6B 24
//Máximos y minimos valores de RPMs que puede conseguir el motor
#define maxPID 66
#define minPID 13
//Máximos y minimos valores de PWM que puede conseguir el motor
#define maxPWM 255
#define minPWM 0
//Sensores de contacto
#define Cont_Der 28 //Sensor de contacto derecho
#define Cont_Izq 30 //Sensor de contacto derecho
/*-------------------------------------------------------------Variables----------------------------------------------------*/
int fotoR[8] = {A0, A1, A2, A3, A4, A5, A6, A7}; //Fotoresistencias
int MD_A = 0; //Valor de dirección del MotorD_A
int MD_B = 0; //Valor de dirección del MotorD_B
int MI_A = 0; //Valor de dirección del MotorI_A
int MI_B = 0; //Valor de dirección del MotorI_B
int pwm_D = 0; //Valor de dirección del Motor_D
int pwm_I = 0; //Valor de dirección del Motor_I
float RPM_der = 0; //Revoluciones por minuto calculadas
float RPM_izq = 0; //Revoluciones por minuto calculadas
float velocidad_der = 0; //Velocidad en [m/s]
float velocidad_izq = 0; //Velocidad en [m/s]
int cambioderecha = 0;
float velocidadder = 0;
int cambioizquierda = 0;
float velocidadizq = 0;
float data[8];
//Almacenaiento de pulsos de cada motor
volatile long ContM1 = 0;
volatile long ContM2 = 0;
volatile long ContM3 = 0;
volatile long ContM4 = 0;
volatile long ContM5 = 0;
volatile long ContM6 = 0;

//Variables para el cálculo de la velocidad
unsigned long timeold = 0;  // Tiempo
unsigned int pulsesperturn = 3200; // Número de pulsos por vuelta del motor, por canal = 3267.  //1600 Según yo recuerdo eran 3200 con el RISING
float wheel_diameter = 123.40 / 1000.0; // Diámetro de la rueda pequeña[mm]  //[m]
int ratio = 1;  // Relación de transmisión

//Definición de variables para el PID derecho
float error_D = 0;
float errorAnterior_D = 0;
float P_D = 0; //Acción proporcional
float I_D = 0; //Acción integral
float D_D = 0; //Acción derivativa
float Kp_D = 35.0;//0.4 //Constante proporcional
float Ki_D = 0.1;//0.025; //Constante integral
float Kd_D = 0.1;//2.9; //Constante derivativa

//Definición de variables para el PID izquierdo
float error_I = 0;
float errorAnterior_I = 0;
float P_I = 0; //Acción Proporcional
float I_I = 0; //Acción integral
float D_I = 0; //Acción /DErivativa
float Kp_I = 40.0;//0.4 //Constante proporcional
float Ki_I = 0.1;//0.025 //Constante integral
float Kd_I = 0.1;//2.9//Constante derivativa
/*
    kp    arranque  direccion
    40 ->  bien     bien
*/
long long int encoDerAvg, encoIzqAvg, totalIzq, totalDer;



//Definición de las señales de error, control y la salida del sistema.
float r_t_D = 0 ; //[m/s]
float r_t_I = 0 ; //[m/s]
float r_tder = 0; //[m/s]
float r_tizq = 0; //[m/s]
volatile float y_t_D = 0;
volatile float y_t_I = 0;
float ut_D = 0;
float ut_I = 0;

//Tiempo del ciclo del PID
float cycleTime = 200; //ms
///Tiempo del ciclo del PID en segundo
//¡NO MODIFICAR, SE CALCULA SOLA!
float cycleTimeSeconds = 0; //s  //Variable auxiliar del tiempo del ciclo del PID
/*--------------------------------------------------------Funciones-------------------------------------------------------*/
//Funciones que recibe las velocidades
void speedsCallback(const std_msgs::Float32MultiArray& msg) {
  if (msg.data_length < 2) {
    r_tizq = 0;
    r_tder = 0;
    return;
  } else {
    r_tizq = msg.data[0];
    r_tder = msg.data[1];
  }
  velocidadder = fabs(r_tder);
  velocidadizq = fabs(r_tizq);
}

//Contador de pulsos del encoder 1
void encoderM1aEvent() {
  if (digitalRead(Enc_M1A) == HIGH) {
    if (digitalRead(Enc_M1B) == LOW)
      ContM1--; //A=1 & B=0
    else
      ContM1++; //A=1 & B=1
  } else {
    if (digitalRead(Enc_M1B) == LOW)
      ContM1++; //A=0 & B=0
    else
      ContM1--; //A=0 & B=1
  }
}
//Contador de pulsos del encoder 2
void encoderM2aEvent() {
  if (digitalRead(Enc_M2A) == HIGH) {
    if (digitalRead(Enc_M2B) == LOW)
      ContM2++; //A=1 & B=0
    else
      ContM2--; //A=1 & B=1
  } else {
    if (digitalRead(Enc_M2B) == LOW)
      ContM2--; //A=0 & B=0
    else
      ContM2++; //A=0 & B=1
  }
}
//Contador de pulsos del encoder 3
void encoderM3aEvent() {
  if (digitalRead(Enc_M3A) == HIGH) {
    if (digitalRead(Enc_M3B) == LOW)
      ContM3--; //A=1 & B=0
    else
      ContM3++; //A=1 & B=1
  } else {
    if (digitalRead(Enc_M3B) == LOW)
      ContM3++; //A=0 & B=0
    else
      ContM3--; //A=0 & B=1
  }
}
//Contador de pulsos del encoder 4
void encoderM4aEvent() {
  if (digitalRead(Enc_M4A) == HIGH) {
    if (digitalRead(Enc_M4B) == LOW)
      ContM4++; //A=1 & B=0
    else
      ContM4--; //A=1 & B=1
  } else {
    if (digitalRead(Enc_M4B) == LOW)
      ContM4--; //A=0 & B=0
    else
      ContM4++; //A=0 & B=1
  }
}
//Contador de pulsos del encoder 5
void encoderM5aEvent() {
  if (digitalRead(Enc_M5A) == HIGH) {
    if (digitalRead(Enc_M5B) == LOW)
      ContM5--; //A=1 & B=0
    else
      ContM5++; //A=1 & B=1
  } else {
    if (digitalRead(Enc_M5B) == LOW)
      ContM5++; //A=0 & B=0
    else
      ContM5--; //A=0 & B=1
  }
}
//Contador de pulsos del encoder 6
void encoderM6aEvent() {
  if (digitalRead(Enc_M6A) == HIGH) {
    if (digitalRead(Enc_M6B) == LOW)
      ContM6++; //A=1 & B=0
    else
      ContM6--; //A=1 & B=1
  } else {
    if (digitalRead(Enc_M6B) == LOW)
      ContM6--; //A=0 & B=0
    else
      ContM6++; //A=0 & B=1
  }
}
//Perfil trapezoidal del velocidad
void calculoVelocidad(){
  if (millis() - timeold >= 10) {
    float tol = 2.0;
    int minDer = 0;
    //filtro por el disparo de encoders
    if ((abs(ContM2) < minDer && ContM2 != 0) || minDer == 0)
      minDer = abs(ContM2);
    if ((abs(ContM4) < minDer && ContM4 != 0) || minDer == 0)
      minDer = abs(ContM4);
    if ((abs(ContM6) < minDer && ContM6 != 0) || minDer == 0)
      minDer = abs(ContM6);

    int minIzq = 0;
    if ((abs(ContM1) < minIzq && ContM1 != 0) || minIzq == 0)
      minIzq = abs(ContM1);
    if ((abs(ContM3) < minIzq && ContM3 != 0) || minIzq == 0)
      minIzq = abs(ContM3);
    if ((abs(ContM5) < minIzq && ContM5 != 0) || minIzq == 0)
      minIzq = abs(ContM5);

    if (abs(ContM1) > tol * minIzq)
      ContM1 = (ContM1 < 0) ? -minIzq : minIzq; //operador ternario por si el niño no estudió :D
    if (abs(ContM3) > tol * minIzq)
      ContM3 = (ContM3 < 0) ? -minIzq : minIzq;
    if (abs(ContM5) > tol * minIzq)
      ContM5 = (ContM5 < 0) ? -minIzq : minIzq;
    if (abs(ContM2) > tol * minDer)
      ContM2 = (ContM2 < 0) ? -minIzq : minIzq;
    if (abs(ContM4) > tol * minDer)
      ContM4 = (ContM4 < 0) ? -minIzq : minIzq;
    if (abs(ContM6) > tol * minDer)
      ContM6 = (ContM6 < 0) ? -minIzq : minIzq;

    encoDerAvg = (ContM2 + ContM4 + ContM6) / 3;
    encoIzqAvg = (ContM1 + ContM3 + ContM5) / 3;
    //periodo maximo de muestreo para la velocidad
    // Uptade every one second, this will be equal to reading frecuency (Hz). // Se actualiza cada segundo
    noInterrupts(); //Don't process interrupts during calculations // Desconectamos la interrupción para que no actué en esta parte del programa.
    //***************************************************************************************
    RPM_der = (1000.0 * 60.0 * (fabs(encoDerAvg) / float(pulsesperturn))) / float(millis() - timeold);
    //RPM_der = 120.0 * (float)abs(ContM4) / (float)pulsesperturn * 1000.0 / float(millis() - timeold) ; // Note that this would be 60*1000/(millis() - timeold)*pulses if the interrupt. happened once per revolution // Calculamos las revoluciones por minuto
    //Ojo con la fórmula de arriba, la variable rpm tiene que ser tipo float porque salen decimales en medio de la operación.
    //velocidad_der = RPM_der *3.1416 * wheel_diameter  / 60; // Cálculo de la velocidad de la rueda en [Km/h]
    velocidad_der = RPM_der * (3.141592 * wheel_diameter) / 60.0; //[m/s]
    ContM2 = 0;  // Inicializamos los pulsos
    ContM4 = 0;  // Inicializamos los pulsos
    ContM6 = 0;  // Inicializamos los pulsos
    //***************************************************************************************
    RPM_izq = (1000.0 * 60.0 * (fabs(encoIzqAvg) / float(pulsesperturn))) / float(millis() - timeold);
    //RPM_izq = 120 * abs(ContM3) / pulsesperturn * 1000 / (millis() - timeold) ; // Note that this would be 60*1000/(millis() - timeold)*pulses if the interrupt. happened once per revolution // Calculamos las revoluciones por minuto
    //Ojo con la fórmula de arriba, la variable rpm tiene que ser tipo float porque salen decimales en medio de la operación.
    //velocidad_izq = RPM_izq *3.1416 * wheel_diameter  / 60; // Cálculo de la velocidad de la rueda en [Km/h]
    velocidad_izq = RPM_izq * (3.141592 * wheel_diameter) / 60.0; //[m/s]
    ContM1 = 0;  // Inicializamos los pulsos.
    ContM3 = 0;  // Inicializamos los pulsos.
    ContM5 = 0;  // Inicializamos los pulsos.

    timeold = millis(); // Almacenamos el tiempo actual.
    interrupts(); // Restart the interrupt processing // Reiniciamos la interrupción
  }
}
/*-----------------------------------------------------------------Control PID-----------------------------------------------------------------------*/
float ut_D_anterior = 0;
float ut_I_anterior = 0;
float pid_tiempo, pid_tiempo_anterior;
float I_D_suma;
float ev, Rplus;
const float krp = 0.001;
//#define krp 5.0

void pid() {
  pid_tiempo = float(millis()) / 1000.0; //[seg]
  //pid velocidades
  ev = velocidad_der - velocidad_izq;
  Rplus = krp * ev;
  //****************PID DERECHO***************************
  y_t_D = velocidad_der;  //real  [m/s]
  r_t_D = velocidadder;   //deseada  [m/s]
  error_D = r_t_D - y_t_D - Rplus;//Cálculo del error
  P_D = Kp_D * error_D;//Acción proporcional
  D_D = Kd_D * (error_D - errorAnterior_D) / (pid_tiempo - pid_tiempo_anterior);
  I_D += Ki_D * 0.5 * (error_D + errorAnterior_D) * (pid_tiempo - pid_tiempo_anterior);
  ut_D = ut_D_anterior + P_D + D_D + I_D;// + I_D + D_D;//suma de las tres acciones para obtener la señal de control
  if (ut_D > 255)  ut_D = 255;
  else if (ut_D < 0) ut_D = 0;

  if (velocidadder == 0) {
    ut_D = 0;
    errorAnterior_D = 0;
    error_D = 0;
  }

  errorAnterior_D = error_D;
  ut_D_anterior = ut_D;
  //****************PID IZQUIERDO****************************
  y_t_I = velocidad_izq;
  r_t_I = velocidadizq;
  error_I = r_t_I - y_t_I + Rplus;//Cálculo del error
  P_I = Kp_I * error_I;//Acción proporcional
  //I_I += Ki_I * error_I * cycleTimeSeconds;// /Calculo acción integrativa
  //D_I = Kd_I * (error_I - errorAnterior_I) / cycleTimeSeconds;//cálculo acción derivativa
  ut_I = ut_I_anterior + P_I + I_I + D_I; //suma de las tres acciones para obtener la señal de control
  if (ut_I > 255)  ut_I = 255;
  else if (ut_I < 0) ut_I = 0;

  if (velocidadizq == 0) {
    ut_I = 0;
    errorAnterior_I = 0;
    error_I = 0;
  }

  errorAnterior_I = error_I;
  ut_I_anterior = ut_I;


  pid_tiempo_anterior = pid_tiempo;
}

//Función que dependiendo del valor de "r_tder" cambia los enables de los encoders
void elecciongiro() {
  if (r_tder < 0) {
    MD_B = 1;
    MD_A = 0;
  }
  else {
    MD_A = 1;
    MD_B = 0;
  }
  if (r_tizq < 0)
  {
    MI_A = 1;
    MI_B = 0;
  }
  else
  {
    MI_B = 1;
    MI_A = 0;
  }
}

void rpmToPwm() {
  //Convertimos el valor de RPMs a PWM
  pwm_I = ut_I;//map(ut_I, minPID, maxPID, minPWM, maxPWM);
  pwm_D = ut_D;//map(ut_D, minPID, maxPID, minPWM, maxPWM);
}
/*-----------------------------------------------------------------ROS--------------------------------------------------------------*/
ros::NodeHandle nh;
std_msgs::Float32MultiArray photoSensors;
std_msgs::Int64 encoderIzq;
std_msgs::Int64 encoderDer;
ros::Subscriber<std_msgs::Float32MultiArray> subSpeeds("/motor_speeds", &speedsCallback);
ros::Publisher pubSensors("/photoSensors", &photoSensors);
ros::Publisher pubEncoIzq("/encoIzq", &encoderIzq);
ros::Publisher pubEncoDer("/encoDer", &encoderDer);


void setup() {
  Serial.begin(115200);
  nh.getHardware()->setBaud(78600);  //Baudaje de comunicación
  nh.initNode();  //Se inicializa el nodo
  nh.advertise(pubSensors);
  nh.advertise(pubEncoIzq);
  nh.advertise(pubEncoDer);
  nh.subscribe(subSpeeds);
  photoSensors.data_length = 8;

  nh.spinOnce();

  //Encoders
  pinMode(Enc_M1A, INPUT);
  pinMode(Enc_M1B, INPUT);
  pinMode(Enc_M2A, INPUT);
  pinMode(Enc_M2B, INPUT);
  pinMode(Enc_M3A, INPUT);
  pinMode(Enc_M3B, INPUT);
  pinMode(Enc_M4A, INPUT);
  pinMode(Enc_M4B, INPUT);
  pinMode(Enc_M5A, INPUT);
  pinMode(Enc_M5B, INPUT);
  pinMode(Enc_M6A, INPUT);
  pinMode(Enc_M6B, INPUT);

  //Motors
  pinMode(PWM_MotorD, OUTPUT);
  pinMode(PWM_MotorI, OUTPUT);
  pinMode(MotorD_A, OUTPUT);
  pinMode(MotorD_B, OUTPUT);
  pinMode(MotorI_A, OUTPUT);
  pinMode(MotorI_A, OUTPUT);

  //Interruptions
  attachInterrupt(0, encoderM1aEvent, CHANGE); //Int0 =Enc_M1A = pin2
  attachInterrupt(1, encoderM2aEvent, CHANGE); //Int1 =Enc_M2A = pin3
  attachInterrupt(5, encoderM3aEvent, CHANGE); //Int5 =Enc_M3A = pin18
  attachInterrupt(4, encoderM4aEvent, CHANGE); //Int4 =Enc_M4A = pin19
  attachInterrupt(3, encoderM5aEvent, CHANGE); //Int3 =Enc_M5A = pin20
  attachInterrupt(2, encoderM6aEvent, CHANGE); //Int2 =Enc_M6A = pin21

  //sensors
  pinMode(Cont_Der, INPUT);
  pinMode(Cont_Izq, INPUT);

  //Set of values
  ContM1 = 0;
  ContM2 = 0;
  ContM3 = 0;
  ContM4 = 0;
  ContM5 = 0;
  ContM6 = 0;
  RPM_der = 0;
  RPM_izq = 0;
  timeold = 0;
  velocidadder = 0;
  velocidadizq = 0;
  r_tizq = 0;
  r_tder = 0;
  cycleTimeSeconds = cycleTime / 1000;
  nh.spinOnce();
}

void emulaVelocidades(float Vizq, float Vder) {
  r_tizq = Vizq;
  r_tder = Vder * 1.025;
  velocidadder = fabs(r_tder);
  velocidadizq = fabs(r_tizq);
}

void loop() {
  Serial.println(ContM3);
  //ligth sensors readings
  for (int i = 0; i < 8; i++)
    data[i] = analogRead(fotoR[i]);
  nh.spinOnce();

  //contact sensors readings
  //data[8]=digitalRead(Cont_Der);
  //data[9]=digitalRead(Cont_Izq);
  //emulaVelocidades(-1*0.387,-1*0.387);  //[m/s] (izq, der)
  elecciongiro();
  calculoVelocidad();
  pid();
  nh.spinOnce();
  rpmToPwm();
  nh.spinOnce();

  //current speeds readings
  //data[10]=velocidad_izq;
  //data[11]=velocidad_der;

  //Direcciones y velocidad de lo motores
  digitalWrite(MotorD_A, MD_A); //Motores Derechos
  nh.spinOnce();
  digitalWrite(MotorD_B, MD_B);
  nh.spinOnce();
  digitalWrite(MotorI_A, MI_A); //Motores Izquierda
  nh.spinOnce();
  digitalWrite(MotorI_B, MI_B);
  nh.spinOnce();

  analogWrite(PWM_MotorD, pwm_D);
  nh.spinOnce();
  analogWrite(PWM_MotorI, pwm_I);
  nh.spinOnce();

  //Serial.println(pwm_D);
  /*Serial.print(velocidad_izq*10);
    Serial.print(",");
    Serial.println(velocidad_der*10);
  */

  photoSensors.data = data;
  totalDer += encoDerAvg;
  totalIzq += encoIzqAvg;
  encoderDer.data = totalDer;
  encoderIzq.data = totalIzq;
  pubSensors.publish(&photoSensors);
  nh.spinOnce();
  pubEncoIzq.publish(&encoderIzq);
  nh.spinOnce();
  pubEncoDer.publish(&encoderDer);
  nh.spinOnce();

  //delay(30);
}

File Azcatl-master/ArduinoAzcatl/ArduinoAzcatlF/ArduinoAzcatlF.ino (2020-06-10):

/*-------------------------------------------------------------
Silva Guzmán Alejandro ->Formato
Dr. Savage Carmona
Septiembre 2019
/*--------------------------------------------------------------*/

/*----------------------Librerías----------------------*/
#include <ros.h>
#include <std_msgs/Int8.h>
#include <std_msgs/Int64.h>  
#include <std_msgs/Int16MultiArray.h> 
#include <std_msgs/Float32.h> 

/*--------------------------Pines--------------------------*/

/*----------------------Motores----------------------*/
#define MotorD_A    50  //Pin de los motores Derechos A
#define MotorD_B    51  //Pin de los motores Derechos B
#define MotorI_A    48  //Pin de los motores Izquierdos A: 52->48
#define MotorI_B    49  //Pin de los motores Izquierdos B: 53->49
#define PWM_MotorD   7  //Pin de los motores Derechos
#define PWM_MotorI   6  //Pin de los motores Izquierdos

/*----------------------Encoders----------------------*/
//Cada motor en llanta cuenta con variables en encoders. Ambas nos sirven para determinar la cantidad de pulsos por revolución.
//posibles del giro de llanta.

//Motor 1 --> Enfrente Derecha
#define Enc_M1A 2     //Interrup0
#define Enc_M1B 4

//Motor 2 --> Enfrente Izquierda
#define Enc_M2A 3     //Interrup1
#define Enc_M2B 5

//Motor 3 --> Medio Derecha
#define Enc_M3A 18    //Interrup5
#define Enc_M3B 17

//Motor 4 --> Medio Izquierda
#define Enc_M4A 19    //Interrup4
#define Enc_M4B 22

 //Motor 5 -->  Atras Derecha
#define Enc_M5A 20    //Interrup3
#define Enc_M5B 23

//Motor 6 --> Atras Izquierda
#define Enc_M6A 21    //Interrup2
#define Enc_M6B 24

/*----------------------Revoluciones/min----------------------*/
//Máximos y minimos valores de RPM que puede conseguir el motor
#define maxPID 66
#define minPID 13

//----------------------Pulse Width Modulation----------------------
//Máximos y minimos valores de PWM que puede conseguir el motor (entiendo 8 bits usados)
#define maxPWM 255
#define minPWM 0

/*----------------------Sensores infrarojo----------------------*/
#define Cont_Der 28   //Sensor de contacto derecho
#define Cont_Izq 30   //Sensor de contacto derecho

/*----------------------Variables----------------------*/

int MD_A = 0;       //Valor de dirección del MotorD_A
int MD_B = 0;       //Valor de dirección del MotorD_B
int MI_A = 0;       //Valor de dirección del MotorI_A
int MI_B = 0;       //Valor de dirección del MotorI_B
int pwm_D = 0;      //Valor de dirección del Motor_D
int pwm_I = 0;      //Valor de dirección del Motor_I
int cambioderecha = 0;
int cambioizquierda = 0;
int fotoR[8] = {A0,A1,A2,A3,A4,A5,A6,A7};  //Fotoresistencias

int data[8];              //Arreglo que almacenara las lecturas de las fotoresistencias.
float RPM_der = 0;        //Revoluciones por minuto calculadas
float RPM_izq = 0;        //Revoluciones por minuto calculadas
float velocidadder = 0;
float velocidadizq = 0;
float velocidad_R = 0;    //Velocidad en [m/s]
float velocidad_L = 0;    //Velocidad en [m/s]

//----------------------Almacenaiento de pulsos de cada motor----------------------
volatile long ContM1=0;
volatile long ContM2=0;
volatile long ContM3=0;
volatile long ContM4=0;
volatile long ContM5=0;
volatile long ContM6=0;

//----------------------Variables para el cálculo de la velocidad----------------------

int ratio = 1;                                            //Relación de transmisión 
float wheel_diameter  = 123.40/1000.0;                    //Diámetro de la rueda pequeña[mm]
float wheel_circunference = wheel_diameter * 3.141592;    //Circunferencia de la rueda
unsigned int pulsesPerWheel_Spin = 3200;                  //Número de pulsos por vuelta desde el encoder de cada motor, por canal = 3267.  //Checar si eran 1600. Recuerdo eran 3200 con el RISING.
unsigned long timeold = 0;                                //Variable de tiempo antigua relativa
long long int encoDerAvg, encoIzqAvg, totalIzq, totalDer;

//------Definición de las señales de error, control y la salida del sistema para el control del PID------

float inputUtFunc_R = 0;            //Salida del accionador, pasando ya por PID derecho en [m/s]
float inputUtFunc_L = 0;            //          ""                ""          izquierdo en [m/s]
float referenceFunc_R = 0;          //Entrada al PID derecho en [m/s]
float referenceFunc_L = 0;          //      ""     izquierdo en [m/s]
float referenceFuncValue_R = 0;     //Valor de entrada al PID derecho en [m/s] deseado desde usuario
float referenceFuncValue_L = 0;     //          ""          izquierdo en [m/s] 
float kpRef = 0;
float kdRef = 0;
float kiRef = 0;      
float kp = 0;
float ki = 0;
float kd = 0;               

volatile float outputFunc_L  = 0;
volatile float outputFunc_R = 0;

//----------------------Funcion que recibe las velocidades----------------------

void speedLCallback(const std_msgs::Float32& msgL){
  referenceFuncValue_L = msgL.data;     //Valores que vienen desde nodo del algoritmo de comportamiento                                mportamiento
  velocidadizq = fabs(referenceFuncValue_L); 
}
void speedRCallback(const std_msgs::Float32& msgR){
  referenceFuncValue_R = msgR.data;     //Valores que vienen desde nodo del algoritmo de comportamiento                     mportamiento
  velocidadder = fabs(referenceFuncValue_R); 
}

//----------------------Funciones que reciben las constantes para el PID----------------------

void kpCallback(const std_msgs::Int8& msg){
  kp = msg.data;        
  //printf("%f",kp);                  
}
void kdCallback(const std_msgs::Int8& msg){
  kd = msg.data;        
  //printf("%f",kd);                  
}
void kiCallback(const std_msgs::Int8& msg){
  ki = msg.data;        
  //printf("%f",ki);                  
}

//----------------------Contador de pulsos del encoder 1----------------------
void encoderM1aEvent(){
  if(digitalRead(Enc_M1A)==HIGH){
    if(digitalRead(Enc_M1B)==LOW)
      ContM1--; //A=1 & B=0
    else
      ContM1++; //A=1 & B=1
  }else{
    if(digitalRead(Enc_M1B)==LOW)
      ContM1++; //A=0 & B=0
    else
      ContM1--; //A=0 & B=1
  }
}

//----------------------Contador de pulsos del encoder 2----------------------
void encoderM2aEvent(){
  if(digitalRead(Enc_M2A)==HIGH){
    if(digitalRead(Enc_M2B)==LOW)
      ContM2++; //A=1 & B=0
    else 
      ContM2--; //A=1 & B=1
  }else{
    if(digitalRead(Enc_M2B)==LOW)
      ContM2--; //A=0 & B=0
    else
      ContM2++; //A=0 & B=1
  }
}

//----------------------Contador de pulsos del encoder 3----------------------
void encoderM3aEvent(){
  if(digitalRead(Enc_M3A)==HIGH){
    if(digitalRead(Enc_M3B)==LOW)
      ContM3--; //A=1 & B=0           
    else 
      ContM3++; //A=1 & B=1              
  }else{
    if(digitalRead(Enc_M3B)==LOW)  
      ContM3++; //A=0 & B=0           
    else 
      ContM3--; //A=0 & B=1               
  }
}
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

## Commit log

2019-09-17 Se clona el Repositorio antiguo
2019-09-17 Eliminacion de Archivos innecesarios
2019-09-17 Actualizacion de README
2019-09-17 Clonacion de archivos desde el repositorio antiguo
    [Arduino_Mega.prt, Azcatl.prt, Azcatl.urdf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]
2019-09-17 Eliminacion de basura
2019-09-17 Update de README
2019-09-24 Update de carrito_control con Hokuyo
2019-09-26 Actualizacion de carrito_control
2019-09-26 Actualizacion de carrito_controL de mis archivos
2019-09-26 Agrego nodo hokuyo para comenzar a interpretarlo y comentarlo
2019-10-01 Actualizacion de nodos y carrito_control
2019-10-08 Update de nodos y agrego maquinas de estado
2019-10-10 Codigo ya compilado, listo para probar en Azcatl
2019-10-15 Actualizacion de nodo evasor_obstaculos
2019-10-15 Actualizacion de evasor_obstaculos
2019-10-15 Actualizacion de mi ultimo codigo
2019-10-18 Actualizacion de evasor_node
2019-10-19 Se actualiza a maquina de estados ya funcionando
2019-10-21 Se actualiza evasor_obstaculos con distancia a recorrer y umbral insertados por usuario
2019-10-22 Agrego nodo de seguidor de luz
2019-10-25 Agrego actualizacion de nodo: seguidor de luz
2019-10-25 Actualizo seguidor_luz ya funcionando. Falta finalinzar maquina de estados
2019-10-30 Agrego seguidor de luz funcionando y simple_move_2
2019-11-06 Agrego imagen de diseño
2019-11-20 Actualizo maquina de estados de seguidor_luz y evasor_obs
2019-11-21 Agrego ultimas versiones de codigos
2020-02-06 Actualizacion de archivos en Publishers y Subscribers
2020-02-07 Versiones finales de hoy
2020-02-14 Actualizacion de ultimo archivo de Arduino con nuevas constantes K de movimiento
2020-03-03 Actualizacion de nodo en Arduino
2020-04-03 Agrego documentos de Fritzing: diagrama electrico
    [Diagrama eléctrico.fzz]
2020-04-17 Agrego diagramas
    [Diagrama eléctrico.fzz]
2020-06-10 Agrego documentacion del robot y actualizacion de algoritmo de evacion de obstaculos
    [Arduino_Mega.prt, Azcatl.prt, Azcatl.urdf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]
2020-06-12 Actualizo algoritmo seguidor de luz y evasor de obstaculos funcionando y con interfaz mejorada
2020-06-13 Mejora de menu en consola en ambos algoritmos
2020-08-06 Actualizo nodo evasor de obstaculos y hokuyo_node con comentarios
2020-08-12 Agrego version final de evasor de obstaculos, listo para probarse
2021-06-11 Agrego máquinas de estado actualizadas y corregidas
2021-06-12 Actualización y corrección de cartas ASM de Máquinas de Estado
2021-06-12 Agrego documento .PDF de Descripción de nuevo Algoritmo "Evasor de Obstáculos y Seguidor de Luz"
2024-03-21 Actualización de Fritzing
    [Diagrama eléctrico Doble.fzz, Diagrama eléctrico Único.fzz]
2024-03-21 Añado "Análisis de Energía" en Ázcatl
2024-03-21 Added Magnetic Declination Estimated Value at BioroboticsLab
